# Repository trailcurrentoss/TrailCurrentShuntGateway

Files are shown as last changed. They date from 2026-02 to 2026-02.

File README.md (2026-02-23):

# TrailCurrent Shunt Gateway

Gateway module that reads battery monitoring data from a Victron BMV battery shunt via serial and transmits the readings over a CAN bus interface. Part of the [TrailCurrent](https://trailcurrent.com) open-source vehicle platform.

## Hardware Overview

- **Microcontroller:** ESP32
- **Function:** Serial-to-CAN bus bridge for Victron BMV battery shunt data
- **Key Features:**
  - Victron BMV VE.Direct serial protocol parsing
  - CAN bus output at 500 kbps
  - Battery voltage, current, SOC, and wattage reporting
  - Hierarchical PCB schematic design with FreeCAD enclosure
  - 8 LED status indicators

## Hardware Requirements

### Components

- **Microcontroller:** ESP32 development board
- **CAN Transceiver:** Vehicle CAN bus interface (TX: GPIO 15, RX: GPIO 13)
- **Serial Input:** Victron BMV VE.Direct connection (Serial2: TX GPIO 17, RX GPIO 16 at 19200 baud)
- **LED Indicators:** 8 status LEDs (GPIOs 32, 33, 26, 14, 23, 19, 17, 4)

### KiCAD Library Dependencies

This project uses the consolidated [TrailCurrentKiCADLibraries](https://github.com/trailcurrentoss/TrailCurrentKiCADLibraries).

**Setup:**

```bash
# Clone the library
git clone git@github.com:trailcurrentoss/TrailCurrentKiCADLibraries.git

# Set environment variables (add to ~/.bashrc or ~/.zshrc)
export TRAILCURRENT_SYMBOL_DIR="/path/to/TrailCurrentKiCADLibraries/symbols"
export TRAILCURRENT_FOOTPRINT_DIR="/path/to/TrailCurrentKiCADLibraries/footprints"
export TRAILCURRENT_3DMODEL_DIR="/path/to/TrailCurrentKiCADLibraries/3d_models"
```

See [KICAD_ENVIRONMENT_SETUP.md](https://github.com/trailcurrentoss/TrailCurrentKiCADLibraries/blob/main/KICAD_ENVIRONMENT_SETUP.md) in the library repository for detailed setup instructions.

## Opening the Project

1. **Set up environment variables** (see Library Dependencies above)
2. **Open KiCAD:**
   ```bash
   kicad EDA/trailer-shunt-can-bus.kicad_pro
   ```
3. **Verify libraries load** - All symbol and footprint libraries should resolve without errors
4. **View 3D models** - Open PCB and press `Alt+3` to view the 3D visualization

### Schematic Sheets

The design uses a hierarchical schematic with dedicated sheets:
- **Root** - Top-level connections
- **Power** - Power distribution and regulation
- **CAN** - CAN bus transceiver interface
- **MCU** - ESP32 microcontroller and support circuits
- **Connectivity** - Serial interface to Victron BMV

## Firmware

See `src/` directory for PlatformIO-based firmware.

**Setup:**
```bash
# Install PlatformIO (if not already installed)
pip install platformio

# Build firmware
pio run

# Upload to board
pio run -t upload
```

### Victron BMV Parameters

The firmware parses the following VE.Direct protocol fields:

| Parameter | Description |
|---|---|
| V | Battery voltage |
| I | Battery current (with sign) |
| P | Power/wattage (with sign) |
| SOC | State of charge |
| TTG | Time to go |
| CE | Consumed energy |
| H1-H12, H17-H18 | Historical data |

### CAN Bus Protocol

The gateway transmits two messages at 500 kbps with a 33ms update cycle:

**Message 0x23** (7 bytes) - Battery basics:

| Byte | Description |
|---|---|
| 0 | Battery voltage (whole) |
| 1 | Battery voltage (decimal) |
| 2 | Current sign |
| 3 | Current (whole) |
| 4 | Current (decimal) |
| 5 | SOC (whole) |
| 6 | SOC (decimal) |

**Message 0x24** (5 bytes) - Power metrics:

| Byte | Description |
|---|---|
| 0 | Wattage sign |
| 1 | Wattage MSB |
| 2 | Wattage LSB |
| 3 | TTG MSB |
| 4 | TTG LSB |

## Manufacturing

- **PCB Files:** Ready for fabrication via standard PCB services (JLCPCB, OSH Park, etc.)
- **BOM Generation:** Export BOM from KiCAD schematic (Tools > Generate BOM)
- **Enclosure:** FreeCAD design included in `CAD/` directory
- **JLCPCB Assembly:** See [BOM_ASSEMBLY_WORKFLOW.md](https://github.com/trailcurrentoss/TrailCurrentKiCADLibraries/blob/main/BOM_ASSEMBLY_WORKFLOW.md) for detailed assembly workflow

## Project Structure

```
├── CAD/                          # FreeCAD enclosure design
├── EDA/                          # KiCAD hardware design files
│   ├── trailer-shunt-can-bus.kicad_pro
│   ├── trailer-shunt-can-bus.kicad_sch  # Root schematic
│   ├── can.kicad_sch             # CAN subsystem
│   ├── connectivity.kicad_sch    # Serial interface
│   ├── mcu.kicad_sch             # MCU subsystem
│   ├── power.kicad_sch           # Power subsystem
│   └── trailer-shunt-can-bus.kicad_pcb  # PCB layout
├── src/                          # Firmware source
│   ├── main.cpp                  # Victron BMV parser and CAN transmitter
│   ├── globals.h                 # Pin definitions and debug macros
│   └── canHelper.h               # CAN bus configuration
└── platformio.ini                # Build configuration
```

## License

MIT License - See LICENSE file for details.

This is open source hardware. You are free to use, modify, and distribute these designs under the terms of the MIT license.

## Contributing

Improvements and contributions are welcome! Please submit issues or pull requests.

## Support

For questions about:
- **KiCAD setup:** See [KICAD_ENVIRONMENT_SETUP.md](https://github.com/trailcurrentoss/TrailCurrentKiCADLibraries/blob/main/KICAD_ENVIRONMENT_SETUP.md)
- **Assembly workflow:** See [BOM_ASSEMBLY_WORKFLOW.md](https://github.com/trailcurrentoss/TrailCurrentKiCADLibraries/blob/main/BOM_ASSEMBLY_WORKFLOW.md)

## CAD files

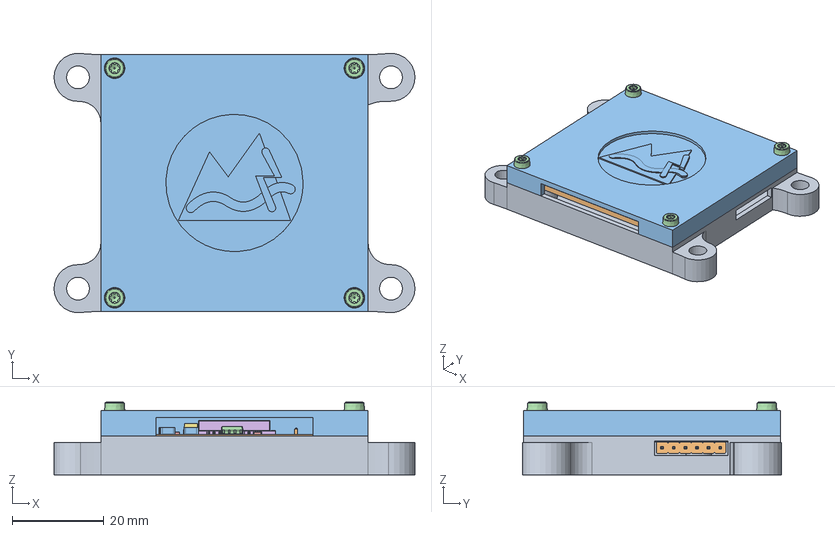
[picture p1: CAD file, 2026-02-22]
CAD/trailer-shunt-can-bus-housing.FCStd
78.9 x 56.6 x 15.8 mm
BodyCaseBottom
Pcb_7b99
C5_C_1206_3216Metric_9f1fbb0e91b7 x 6
U2_SOIC_8_39x49mm_P127mm_3940626bae83
R4_R_1206_3216Metric_6f3765b3a8a0 x 2
AP63203WU-7
AP63203WU-008
AP63203WU-009
AP63203WU-010
AP63203WU-011
AP63203WU-012
AP63203WU-013
AP63203WU-014
U1_ESP32-WROOM-32_805435b90435
FilletPin1
FilletPin2
J1_PinHeader_1x06_P254mm_Horizontal_b900b64528b3
BodyCaseCover
M2.5x8-Screw x 4

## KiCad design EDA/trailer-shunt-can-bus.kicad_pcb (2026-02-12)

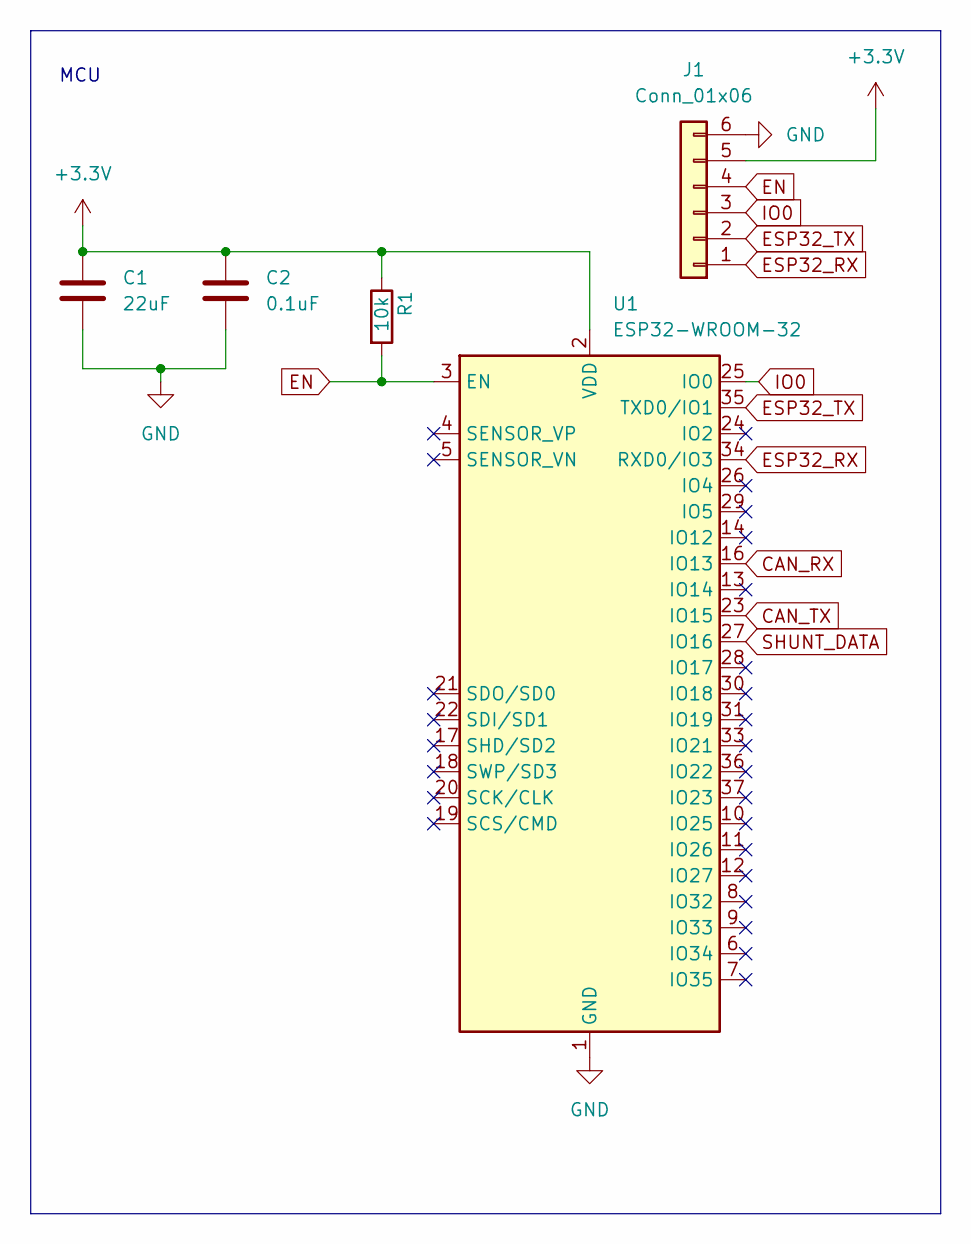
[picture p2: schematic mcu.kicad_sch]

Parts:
C1: 22uF; C_1206_3216Metric_Pad1.33x1.80mm_HandSolder
C2: 0.1uF; C_1206_3216Metric_Pad1.33x1.80mm_HandSolder
J1: Conn_01x06; PinHeader_1x06_P2.54mm_Horizontal
R1: 10k; R_1206_3216Metric_Pad1.30x1.75mm_HandSolder
U1: ESP32-WROOM-32

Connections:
+3.3V: C1.1, C2.1, J1.5, R1.1, U1.2 (VDD); also elsewhere on the board
CAN_RX: U1.16 (IO13); also elsewhere on the board
CAN_TX: U1.23 (IO15); also elsewhere on the board
EN: J1.4, R1.2, U1.3 (EN)
ESP32_RX: J1.1, U1.34 (RXD0/IO3)
ESP32_TX: J1.2, U1.35 (TXD0/IO1)
GND: C1.2, C2.2, J1.6, U1.1 (GND), U1.15 (GND), U1.38 (GND), U1.39 (GND); also elsewhere on the board
IO0: J1.3, U1.25 (IO0)
SHUNT_DATA: U1.27 (IO16); also elsewhere on the board

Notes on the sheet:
MCU

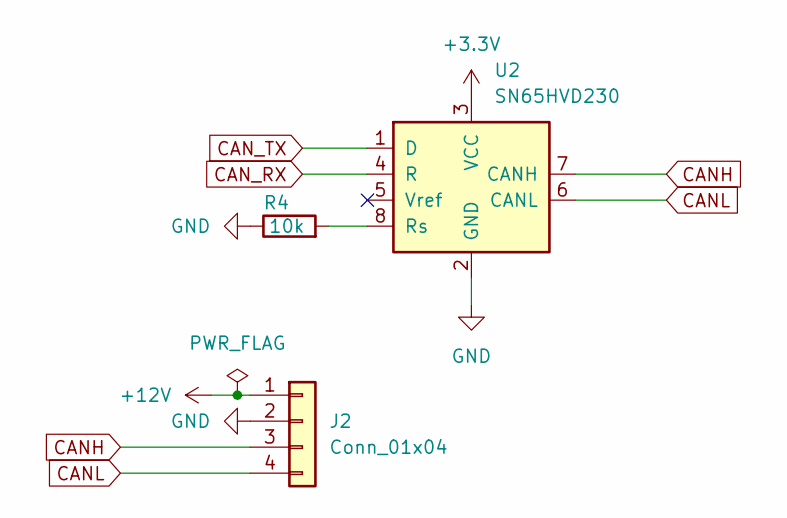
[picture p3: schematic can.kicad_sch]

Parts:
J2: Conn_01x04; CAN_PLUS_POWER
R4: 10k; R_1206_3216Metric_Pad1.30x1.75mm_HandSolder
U2: SN65HVD230; SOIC-8_3.9x4.9mm_P1.27mm

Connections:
+3.3V: U2.3 (VCC); also elsewhere on the board
+12V: J2.1; also elsewhere on the board
CANH: J2.3, U2.7 (CANH)
CANL: J2.4, U2.6 (CANL)
CAN_RX: U2.4 (R); also elsewhere on the board
CAN_TX: U2.1 (D); also elsewhere on the board
GND: J2.2, R4.1, U2.2 (GND); also elsewhere on the board
unnamed: R4.2, U2.8 (Rs)

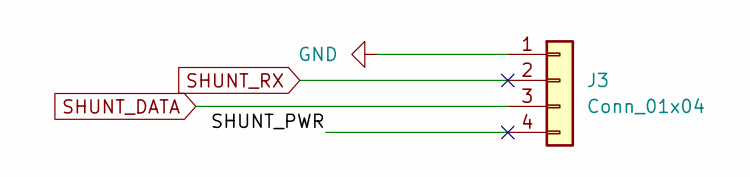
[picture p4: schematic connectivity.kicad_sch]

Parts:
J3: Conn_01x04; GenericPad_01x04

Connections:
/Connectivity/SHUNT_PWR: J3.4
GND: J3.1; also elsewhere on the board
SHUNT_DATA: J3.3; also elsewhere on the board
SHUNT_RX: J3.2

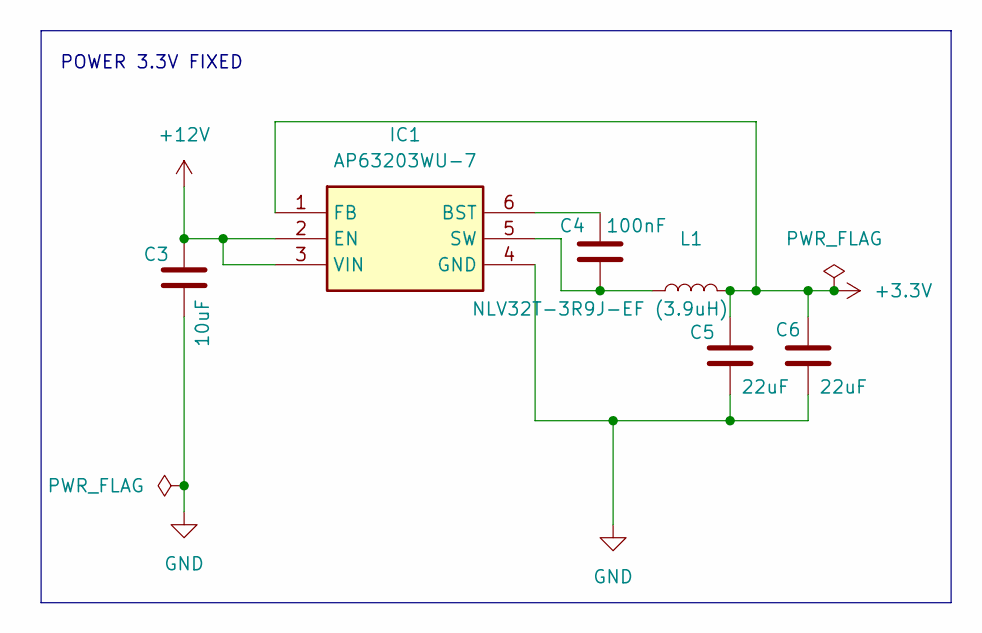
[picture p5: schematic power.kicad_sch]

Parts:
C3: 10uF; C_1206_3216Metric
C4: 100nF; C_1206_3216Metric
C5, C6: 22uF; C_1206_3216Metric_Pad1.33x1.80mm_HandSolder
IC1: AP63203WU-7; AP63203WU7; Mouser Part Number 621-AP63203WU-7
L1: NLV32T-3R9J-EF (3.9uH); NLV32T-3R9J-EF

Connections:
+3.3V: C5.1, C6.1, IC1.1 (FB), L1.2; also elsewhere on the board
+12V: C3.1, IC1.2 (EN), IC1.3 (VIN); also elsewhere on the board
GND: C3.2, C5.2, C6.2, IC1.4 (GND); also elsewhere on the board
unnamed: C4.1, IC1.6 (BST)
unnamed: C4.2, IC1.5 (SW), L1.1

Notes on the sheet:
POWER 3.3V FIXED

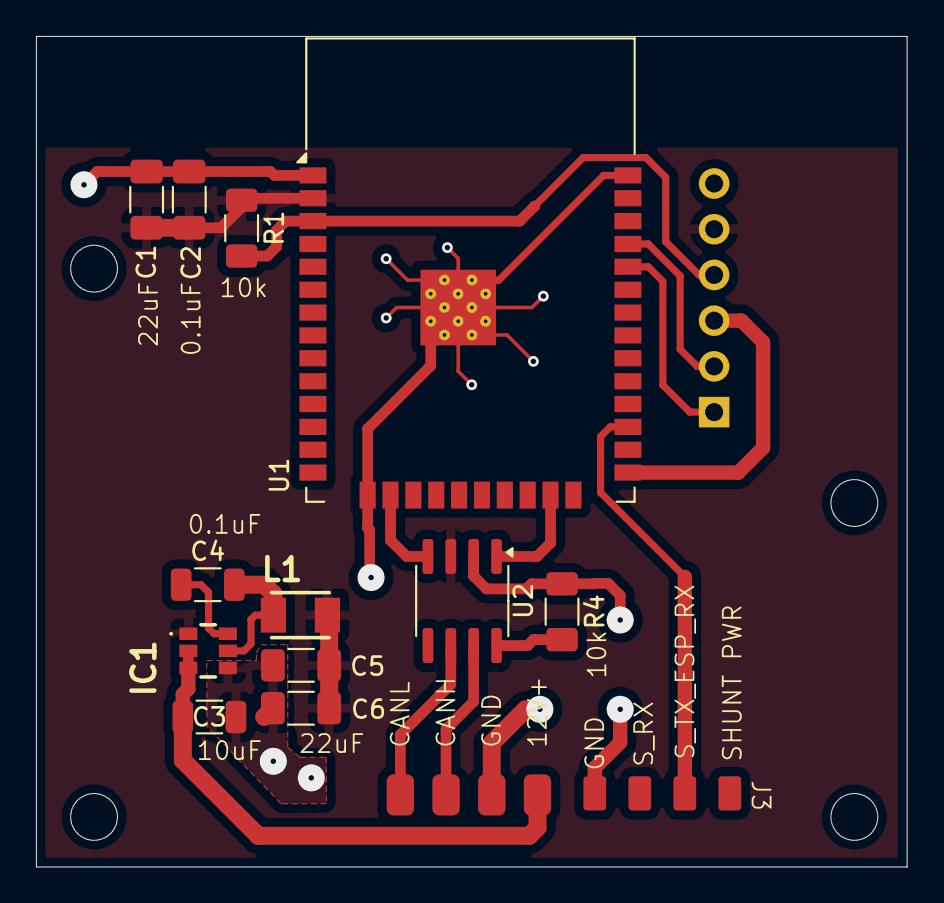
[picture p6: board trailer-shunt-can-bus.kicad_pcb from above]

Board: 2 copper layers, 48.4 x 46.1 mm, 15 parts (1 on the bottom side), 15 nets.

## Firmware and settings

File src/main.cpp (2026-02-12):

#include <Arduino.h>
#include "globals.h"
#include "canHelper.h"

#define CAN_SEND_MESSAGE_SHUNT01_IDENTIFIER 0x23;
#define CAN_SEND_MESSAGE_SHUNT02_IDENTIFIER 0x24;

volatile int batteryVoltageWholeNumber;
volatile int batteryVotlageDecimal;
volatile int isShuntCurrentNegative;
volatile int shuntCurrentWholeNumber;
volatile int shuntCurrentDecimal;
volatile int batterySocWholeNumber;
volatile int batterySocDecimal;
volatile int isWattageInUseNegative;
volatile int wattageInUse;
volatile byte wattageMsb;
volatile byte wattageLsb;
volatile byte wattageNegativeIndicator;
volatile byte ttgMsb;
volatile byte ttgLsb;

unsigned long canStartMillis;
unsigned long canCurrentMillis;
const unsigned long canStatusPeriod = 33;

static void send_batt_message()
{
  // Configure message to transmit
  twai_message_t message;
  message.identifier = CAN_SEND_MESSAGE_SHUNT01_IDENTIFIER;
  message.extd = false;
  message.rtr = false;
  message.data_length_code = 7;
  message.data[0] = batteryVoltageWholeNumber;
  message.data[1] = batteryVotlageDecimal;
  message.data[2] = isShuntCurrentNegative;
  message.data[3] = shuntCurrentWholeNumber;
  message.data[4] = shuntCurrentDecimal;
  message.data[5] = batterySocWholeNumber;
  message.data[6] = batterySocDecimal;
  // Queue message for transmission
  if (twai_transmit(&message, pdMS_TO_TICKS(10)) == ESP_OK)
  {
    // debugln("Message queued for transmission");
  }
  else
  {
    // debugln("Failed to queue message for transmission");
  }
  return;
}

static void send_batt_message_01()
{
  // Configure message to transmit
  twai_message_t message;
  message.identifier = CAN_SEND_MESSAGE_SHUNT02_IDENTIFIER;
  message.extd = false;
  message.rtr = false;
  message.data_length_code = 5;
  message.data[0] = wattageNegativeIndicator;
  message.data[1] = wattageMsb;
  message.data[2] = wattageLsb;
  message.data[3] = ttgMsb;
  message.data[4] = ttgLsb;
  // Queue message for transmission
  if (twai_transmit(&message, pdMS_TO_TICKS(10)) == ESP_OK)
  {
    // debugln("Message queued for transmission");
  }
  else
  {
    // debugln("Failed to queue message for transmission");
  }
  return;
}

void setup()
{
  Serial.begin(115200); // Used for debugging and logging
  while (!Serial)
  {
    ;
    ;
  }
  Serial2.begin(19200);
  canHelper::canSetup();
}

void loop()
{
  canCurrentMillis = millis();
  if (canCurrentMillis - canStartMillis >= canStatusPeriod)
  {
    while (Serial2.available())
    {
      String input = Serial2.readStringUntil('\n');
      // Split the input string based on the delimiter "]t"
      int startIndex = 0;
      int delimiterIndex = 0;

      while ((delimiterIndex = input.indexOf("\t", startIndex)) != -1)
      {
        // Extract the key (substring from startIndex to delimiterIndex)
        String key = input.substring(startIndex, delimiterIndex);
        startIndex = delimiterIndex + 1; // Move past the "]t" delimiter

        // Extract the value (substring from startIndex to the next delimiter or end of string)
        int nextDelimiterIndex = input.indexOf("\t", startIndex);
        String value;
        if (nextDelimiterIndex != -1)
        {
          value = input.substring(startIndex, nextDelimiterIndex);
          startIndex = nextDelimiterIndex + 2; // Move past the "\t" delimiter
        }
        else
        {
          value = input.substring(startIndex); // Handle last key-value pair (no delimiter after value)
        }

        if (key == "V")
        {
          float voltageValue = (value.toInt() * 0.001);
          batteryVoltageWholeNumber = (int)voltageValue;                                   // First we get the whole number voltage.
          batteryVotlageDecimal = (int)((voltageValue - batteryVoltageWholeNumber) * 100); // For 2 decimal places
        }
        else if (key == "VPV")
        {
          // debug("Panel Voltage: ");
          // debugln(value);
        }
        else if (key == "PPV")
        {
          // debug("Panel Power: ");
          // debugln(value);
        }
        else if (key == "I")
        {
          float currentValue = (value.toInt() * 0.001);
          shuntCurrentWholeNumber = (int)currentValue;
          shuntCurrentDecimal = (int)((currentValue - shuntCurrentWholeNumber) * 100);
          if (currentValue < 0)
          {
            isShuntCurrentNegative = 1;
          }
          else
          {
            isShuntCurrentNegative = 0;
          }
          // debug("Current: ");
          // debug(currentValue);
          // debugln(" A");
        }
        else if (key == "P")
        {
          wattageInUse = value.toInt();
          byte signByte = (wattageInUse < 0) ? 0xFF : 0x00; // MSB (Most Significant Bit) is set for negative numbers
          // Get the absolute value of the number
          unsigned int absValue = abs(wattageInUse);
          // Break the absolute value into 2 bytes
          byte lowByte = absValue & 0xFF;         // Least significant byte
          byte highByte = (absValue >> 8) & 0xFF; // Most significant byte          
          // Store the sign byte and the two data bytes
          wattageNegativeIndicator = signByte;
          wattageMsb = highByte;
          wattageLsb = lowByte;
        }
        else if (key == "CE")
        {
          float consumedPowerValue = (value.toInt() * 0.001);
          // debug("Consumed Ah: ");
          // debug(consumedPowerValue);
          // debugln(" A");
        }
        else if (key == "SOC")
        {
          float battSoc = (value.toInt() * 0.1);
          batterySocWholeNumber = (int)battSoc;
          batterySocDecimal = (int)((battSoc - batterySocWholeNumber) * 100);
        }
        else if (key == "TTG")
        {
          // debug("Time Remaining: ");
          // float ttgValue = (value.toInt() / 60);
          // debug(ttgValue);
          // debugln("hrs");
          int number = value.toInt();
          ttgMsb = (number >> 8) & 0xFF;  // Most significant byte
          ttgLsb = number & 0xFF;         // Least significant byte         
        }
        else if (key == "Alarm")
        {
          // debug("Alarm Condition: ");
          // debugln(value);
        }
        else if (key == "AR")
        {
          // debug("Alarm Reason: ");
          // debugln(value);
        }
        else if (key == "Relay")
        {
          // debug("Relay State: ");
          // debugln(value);
        }
        else if (key == "H1")
        {
          // debug("Depth of Deepest Discharge: ");
          // debugln(value);
        }
        else if (key == "H2")
        {
          // debug("Depth of Last Discharge: ");
          // debugln(value);
        }
        else if (key == "H3")
        {
          // debug("Depth of Average Discharge: ");
          // debugln(value);
        }
        else if (key == "H4")
        {
          // debug("Number of Charge Cycles: ");
          // debugln(value);
        }
        else if (key == "H5")
        {
          // debug("Number of Full Discharges: ");
          // debugln(value);
        }
        else if (key == "H6")
        {
          // debug("Cumulative Amp Hours Drawn: ");
          // debugln(value);
        }
        else if (key == "H7")
        {
          float minVoltageValue = (value.toInt() * 0.001);
          // debug("Minimum Main Battery Voltage: ");
          // debug(minVoltageValue);
          // debugln(" V");
        }
        else if (key == "H8")
        {
          float maxVoltageValue = (value.toInt() * 0.001);
          // debug("Maximum Main Battery Voltage: ");
          // debug(maxVoltageValue);
          // debugln(" V");
        }
        else if (key == "H9")
        {
          // debug("Seconds since last full charge: ");
          // debugln(value);
        }
        else if (key == "H10")
        {
          // debug("Number of automatic syncs: ");
          // debugln(value);
        }
        else if (key == "H11")
        {
          // debug("Number of low main voltage alarms: ");
          // debugln(value);
        }
        else if (key == "H12")
        {
          // debug("Number of high main voltage alarms: ");
          // debugln(value);
        }
        else if (key == "H17")
        {
          // debug("Amount of discharded energy: ");
          // debugln(value);
        }
        else if (key == "H18")
        {
          // debug("Amount of charged energy: ");
          // debugln(value);
        }
        else if (key == "BMV")
        {
          // debug("Model: ");
          // debugln(value);
        }
        else if (key == "FW")
        {
          // debug("Firmware Version: ");
          // debugln(value);
        }
        else if (key == "PID")
        {
          // debug("Product ID: ");
          // debugln(value);
        }
      }
    }
    canHelper::canLoop();
    send_batt_message();
    send_batt_message_01();
    canStartMillis = canCurrentMillis;
  }
}

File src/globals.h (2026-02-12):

#pragma once
#include <Arduino.h>
#include "driver/twai.h"

#define LED1_PIN 32
#define LED2_PIN 33
#define LED3_PIN 26
#define LED4_PIN 14
#define LED5_PIN 23
#define LED6_PIN 19
#define LED7_PIN 17
#define LED8_PIN 4

#define DEBUG 0 // This sets whether or not the Serial.println and Serial.print will even be compiled

// Conditional definition for debugging if DEBUG is 1 then it will print to serial port.
// If DEBUG = 0 then the lines will be removed by the compiler.
#if DEBUG == 1
#define debug(x) Serial.print(x)
#define debugln(x) Serial.println(x)
#define debugf(x,y) Serial.printf(x,y)
#define debugg(x,y,z) Serial.printf(x,y,z)
#else
#define debug(x)
#define debugln(x)
#define debugf(x,y)
#define debugg(x,y,z)
#endif

namespace globals {

}

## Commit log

2026-02-12 Starting project
    [can.kicad_sch, connectivity.kicad_sch, mcu.kicad_sch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]
2026-02-22 Updated housing to have logo
    [trailer-shunt-can-bus-housing.FCStd]
